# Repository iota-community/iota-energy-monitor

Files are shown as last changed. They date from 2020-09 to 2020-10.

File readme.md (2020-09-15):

# IOTA Energy Monitor

IOTA Energy Monitor

The IOTA Energy Monitor is a hardware and software project that is designed to take power and meter readings over Modbus and via CT Clamps. The device is also equipped with a CryptoCore module to enable it to issue IOTA transactions and manage funds securely. 

This repo is split into two parts:

### /hardware

This portion of the repo contains the design files for the IOTA Energy Monitor. The device was designed in EAGLE by Autodesk. 

The repo contains the lasted Gerber files in a .zip for easy reproduction.

### /software

This folder contains the micropython software for the energy meter. In order to flash it you should use the Pymakr extension of VSCode.

##### License

Apache 2.0

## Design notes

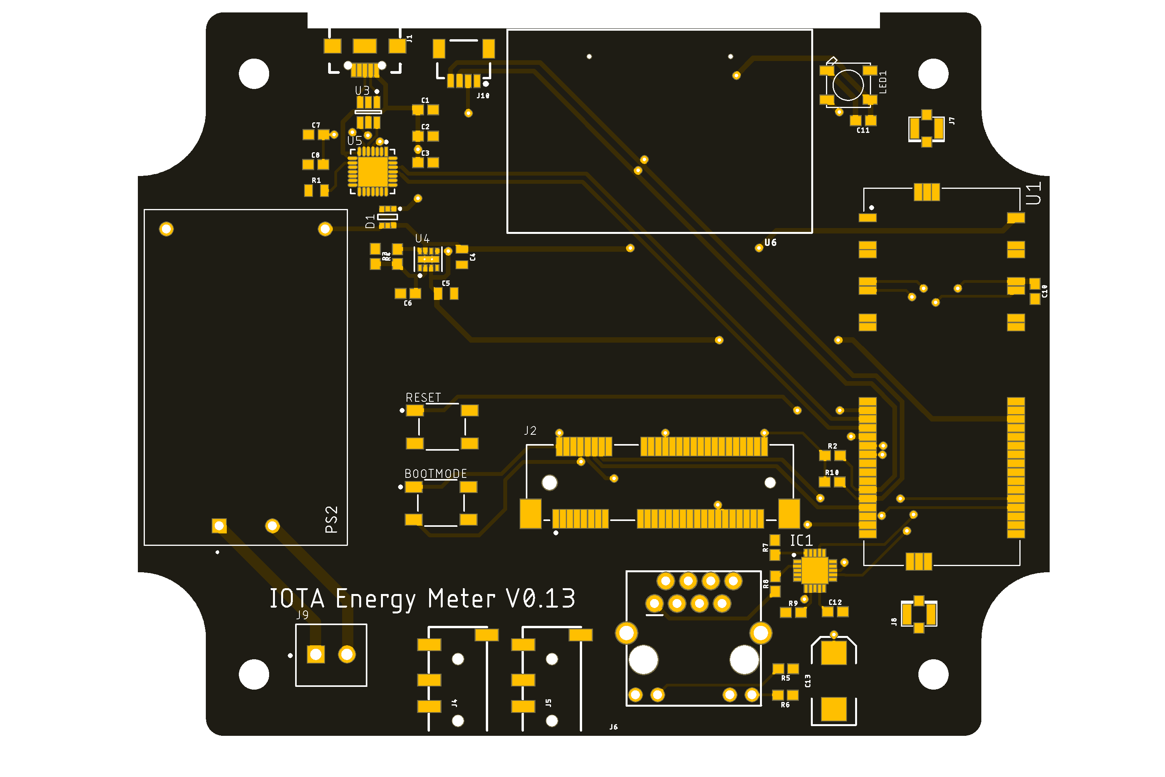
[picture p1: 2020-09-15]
hardware/iota-energy-monitor.png

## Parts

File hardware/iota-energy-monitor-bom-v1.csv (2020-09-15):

Qty | Value | Device | Package | Parts | Description | AMBIENT_TEMPERATURE_RANGE_HIGH | AMBIENT_TEMPERATURE_RANGE_LOW | AUTOMOTIVE | AVAILABILITY | CENTROID_NOT_SPECIFIED | CIIVA_IDS | COMPONENT_LINK_1_DESCRIPTION | COMPONENT_LINK_1_URL | COMPONENT_LINK_3_DESCRIPTION | COMPONENT_LINK_3_URL | CONFIGURATION | CONN_GENDER | CONN_ORIENTATION | CONTACT_MATERIAL | CURRENT_RATING | DATASHEET | DATASHEET_VERSION | DESCRIPTION | DEVICE_CLASS_L1 | DEVICE_CLASS_L2 | DEVICE_CLASS_L3 | DIGIKEY_DESCRIPTION | DIGIKEY_PART_NUMBER | FOOTPRINT_PARAMETERS_1 | FOOTPRINT_PARAMETERS_2 | FOOTPRINT_PARAMETERS_3 | FOOTPRINT_URL | FOOTPRINT_VARIANT_NAME_0 | FOOTPRINT_VARIANT_NAME_1 | FOOTPRINT_VARIANT_NAME_2 | FOOTPRINT_VARIANT_NAME_3 | HEIGHT | IMPORTED | IMPORTED_FROM | IMPORT_TS | INTERFACE | IPC_LAND_PATTERN_NAME | IS_FEMALE | LEAD_FREE | MANUFACTURER_NAME | MANUFACTURER_PART_NUMBER | MAX_JUNCTION_TEMP | MAX_SUPPLY_VOLTAGE | MEMORY_TYPE | MF | MFG_PACKAGE_IDENT | MFG_PACKAGE_IDENT_DATE | MFG_PACKAGE_IDENT_REV | MIN_SUPPLY_VOLTAGE | MOUNTING_TECHNOLOGY | MOUSER_DESCRIPTION | MOUSER_PART_NUMBER | MOUSER_PRICE-STOCK | MP
1 |  | PRT-14417 | 1X04_1MM_RA | J10 | SparkFun I2C Standard Qwiic Connector
1 |  | 1981568-1 | USB-B-MICRO-SMD | J1 | USB Type Micro-B Connector
4 | 0.1uF | C0603X104J3RACAUTO | 603 | C2, C7, C10, C11 | 0.1µF ceramic capacitors
1 | 100 | CRGCQ0603F100R | 603 | R7 | 100Ω resistor
1 | 100uF | KEMETT491D107K010AT | EIA7343 | C13 | 100µF polarized capacitors
1 | 10nF | CC0603KRX7R9BB103 | 603 | C1 | 0.01uF/10nF/10,000pF ceramic capacitors
2 | 10uF | CC0805KKX5R6BB106 | 805 | C4, C5 | 10.0µF ceramic capacitors
2 | 10uF | F380J106MMA | 0603-POLAR | C9, C14 | 10.0µF polarized capacitors
1 | 10uF | GRM188R60J106ME84D | 0805-NO | C22 | Ceramic Capacitors
1 | 118k | RK73H1JTTD1183F | 603 | R4 | Generic Resistor Package
1 | 13k | RC0603FR-0713KL | 603 | R9 | 13kΩ resistor
1 | 150k | RC0603FR-07150KL | 603 | R3 | 150kΩ resistor
1 | 1k | CRGCQ0805F1K0 | 805 | R1 | Generic Resistor Package
5 | 2.2uF | CC0805KKX7R6BB225 | 0805-NO | C20, C21, C23, C24, C25 | Ceramic Capacitors
2 | 20 | RP73PF1J20RBTDF | 603 | R12, R13 | RES-07862
3 | 220 | RC0603JR-07220RL | 603 | R5, R6, R8 | 220Ω resistor
1 | 390K | RC0805FR-07390KL | 0805-NO | R11 | Resistors
2 | 390k | RC0603FR-07390KL | 603 | R14, R15 | 390kΩ resistor
1 | 390nF | C0603C394K8PACTU | 603 | C12 | 0.39uF/390nF ceramic capacitors
2 | 4.7k | RC0603FR-074K7L | 603 | R2, R10 | 4.7kΩ resistor
2 | 4.7uF | CC0603ZRY5V5BB475 | 603 | C3, C8 | 4.7µF ceramic capacitors
1 | 470pF | 06035A471JAT2A | 603 | C6 | 470pF ceramic capacitors
2 | ALPS_SKQGAKE010ALPS_SKQGAKE010_0_0 | ALPS SKQGAKE010 | ALPS_SKQGAKE010_0 | BOOTMODE, RESET | 5.2mm Square Low-profile |  |  |  |  | No |  |  |  |  |  |  |  |  |  |  | http://www.mouser.com/ds/2/15/SKQG-180836.pdf |  |  |  |  |  |  |  |  |  |  |  |  |  |  |  |  |  |  |  |  |  |  | yes |  |  |  |  |  | ALPS |  |  |  |  |  |  | 688-SKQGAKE010
1 | ALPS_SKQGAKE010ALPS_SKQGAKE010_0_0 | ALPS SKQGAKE010 | ALPS_SKQGAKE010_0 | BOOTLOADER | 5.2mm Square Low-profile |  |  |  |  | No |  |  |  |  |  |  |  |  |  |  | http://www.mouser.com/ds/2/15/SKQG-180836.pdf |  |  |  |  |  |  |  |  |  |  |  |  |  |  |  |  |  |  |  |  |  |  | yes |  |  |  |  |  | ALPS |  |  |  |  |  |  | 688-SKQGAKE010
2 | AUDIO_JACK_TRRSSMD_RA | SJ2-3573A-SMT-TR | AUDIO_JACK_3.5MM_TRRS_SMD_RA | J4, J5 | Audio Jack - 3.5mm TRRS (SMD)
1 | HLK-5M05 | HLK-5M05 | CONV_HLK-5M05 | PS2 | AC DC 220V to 5V 5W 5Watt Isolated Switching Step-Down Power Supply Module Converter |  |  |  | Unavailable |  |  |  |  |  |  |  |  |  |  |  |  |  |  |  |  |  |  |  |  |  |  |  |  |  |  |  |  |  |  |  |  |  |  |  |  |  |  |  |  | Hi-link |  |  |  |  |  |  |  |  | HLK-5M05
1 | MAGJACK | ARJM11A1-009-AB-EW2 | MAGJACK | J6 | MAGJACK: RJ-45 with LEDs
1 | NCN5151 | NCN5151 | QFN50P400X400X100-21N | IC1 | NCN5150 Wired M-BUS Slave Transceiver |  |  |  |  |  |  |  |  |  |  |  |  |  |  |  |  |  | NCN5150 Wired M-BUS Slave Transceiver |  |  |  |  |  |  |  |  |  |  |  |  |  | 1mm |  |  |  |  |  |  |  | ON Semiconductor | NCN5151 |  |  |  |  |  |  |  |  |  |  | N/A | https://www.mouser.com/Search/Refine.aspx?Keyword=N%2FA
1 | ON_SEMICONDUCTOR_MBD330DWT1GON_SEMICONDUCTOR_MBD330DWT1G_0_0 | MBD330DWT1G | ON_SEMICONDUCTOR_MBD330DWT1G_0 | D1 | ONSC-SBD-A1K3A4K6-6 |  |  |  |  |  | 849672 | Manufacturer URL | http://www.onsemi.com/ | Package Specification | http://www.onsemi.com/pub_link/Collateral/NTJD4001N-D.PDF | Dual |  |  |  |  | http://www.onsemi.cn/pub_link/Collateral/MBD110DWT1-D.PDF | Rev. 8 |  |  |  |  |  |  |  |  |  |  | Manufacturer Recommended |  |  |  |  | yes | vault | 1521844986 |  |  |  |  |  |  |  |  |  | On Semiconductor |  |  |  |  | Surface Mount
1 | PYCOME-G01-OEM | Pycom G01 | PYCOM_PYCOME-G01-OEM | U1 | The G01 is the GPy OEM module. It’s just like the GPy but with a few bits less to make it easy to integrate. Triple network module: Cellular LTE-CAT M1/NB1, WiFi and Bluetooth. |  |  |  | Unavailable |  |  |  |  |  |  |  |  |  |  |  |  |  |  |  |  |  |  |  |  |  |  |  |  |  |  |  |  |  |  |  |  |  |  |  |  |  |  |  |  | Pycom |  |  |  |  |  |  |  |  | PYCOME-G01-OEM
1 | SILICON_LABS_CP2102N-A01-GQFN28SILICON_LABS_CP2102N-A01-GQFN28_0_3 | CP2102N-A01-GQFN28 | SILICON_LABS_CP2102N-A01-GQFN28_3 | U5 | USB Bridge, USB to UART USB 2.0 UART Interface 28-QFN (5x5) | +85°C | -40°C | No |  | No |  |  |  |  |  |  |  |  |  |  | https://media.digikey.com/pdf/Data%20Sheets/Silicon%20Laboratories%20PDFs/CP2102N_Rev.1.3_DS.pdf |  |  | Integrated Circuits (ICs) | Interface ICs | USB Interface ICs | IC BRIDGE USB TO UART 28QFN | 336-3694-ND | {fp_type":"QFN","params":{"N1":{"nom":7,"long name":"Leads on long side","min":null,"max":null,"short name":"N1","type":"count"},"N2":{"nom":7,"long name":"Leads on wide side","min":null,"max":null,"short name":"N2","type":"count"},"A":{"nom":750000,"long name":"Height","min":700000,"max":800000,"short name":"A","type":"measurement"},"A1":{"nom":false,"long name":"Package clearance","min":0,"max":50000,"short name":"A1","type":"measurement"},"A2":{"nom":false,"long name":"Package height","min":false,"max":750000,"short name":"A2","type":"measurement"},"D":{"nom":5000000,"long name":"Package length","min":4900000,"max":5100000,"short name":"D","type":"measurement"},"E":{"nom":5000000,"long name":"Package width","min":4900000,"max":5100000,"short name":"E","type":"measurement"},"B":{"nom":250000,"long name":"Lead width","min":200000,"max":300000,"short name":"B","type":"measurement"},"C":{"nom":200000,"long name":"Lead thickness","min":null,"max":null,"short name":"C","type":"measurement"},"L":{"nom":550000,"long name":"Lead foot length","min":450000,"max":650000,"short name":"L","type":"measurement"},"e":{"nom":500000,"long name":"Lead pitch","min":null,"max":null,"short name":"e","type":"measurement"},"D2":{"nom":3250000,"long name":"Thermal pad length","min":3150000,"max":false,"short name":"D2","type":"measurement"},"E2":{"nom":3250000,"long name":"Thermal pad width","min":3150000,"max":false,"short name":"E2","type":"measurement"},"PC":{"long name":"Paste coverage (%)","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 | {fp_type":"QFN","params":{"N1":{"nom":7,"long name":"Leads on long side","min":null,"max":null,"short name":"N1","type":"count"},"N2":{"nom":7,"long name":"Leads on wide side","min":null,"max":null,"short name":"N2","type":"count"},"A":{"nom":750000,"long name":"Height","min":700000,"max":800000,"short name":"A","type":"measurement"},"A1":{"nom":false,"long name":"Package clearance","min":0,"max":50000,"short name":"A1","type":"measurement"},"A2":{"nom":false,"long name":"Package height","min":false,"max":750000,"short name":"A2","type":"measurement"},"D":{"nom":5000000,"long name":"Package length","min":4900000,"max":5100000,"short name":"D","type":"measurement"},"E":{"nom":5000000,"long name":"Package width","min":4900000,"max":5100000,"short name":"E","type":"measurement"},"B":{"nom":250000,"long name":"Lead width","min":200000,"max":300000,"short name":"B","type":"measurement"},"C":{"nom":200000,"long name":"Lead thickness","min":null,"max":null,"short name":"C","type":"measurement"},"L":{"nom":550000,"long name":"Lead foot length","min":450000,"max":650000,"short name":"L","type":"measurement"},"e":{"nom":500000,"long name":"Lead pitch","min":null,"max":null,"short name":"e","type":"measurement"},"D2":{"nom":3250000,"long name":"Thermal pad length","min":3150000,"max":false,"short name":"D2","type":"measurement"},"E2":{"nom":3250000,"long name":"Thermal pad width","min":3150000,"max":false,"short name":"E2","type":"measurement"},"PC":{"long name":"Paste coverage (%)","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 | {fp_type":"QFN","params":{"N1":{"nom":7,"long name":"Leads on long side","min":null,"max":null,"short name":"N1","type":"count"},"N2":{"nom":7,"long name":"Leads on wide side","min":null,"max":null,"short name":"N2","type":"count"},"A":{"nom":750000,"long name":"Height","min":700000,"max":800000,"short name":"A","type":"measurement"},"A1":{"nom":false,"long name":"Package clearance","min":0,"max":50000,"short name":"A1","type":"measurement"},"A2":{"nom":false,"long name":"Package height","min":false,"max":750000,"short name":"A2","type":"measurement"},"D":{"nom":5000000,"long name":"Package length","min":4900000,"max":5100000,"short name":"D","type":"measurement"},"E":{"nom":5000000,"long name":"Package width","min":4900000,"max":5100000,"short name":"E","type":"measurement"},"B":{"nom":250000,"long name":"Lead width","min":200000,"max":300000,"short name":"B","type":"measurement"},"C":{"nom":200000,"long name":"Lead thickness","min":null,"max":null,"short name":"C","type":"measurement"},"L":{"nom":550000,"long name":"Lead foot length","min":450000,"max":650000,"short name":"L","type":"measurement"},"e":{"nom":500000,"long name":"Lead pitch","min":null,"max":null,"short name":"e","type":"measurement"},"D2":{"nom":3250000,"long name":"Thermal pad length","min":3150000,"max":false,"short name":"D2","type":"measurement"},"E2":{"nom":3250000,"long name":"Thermal pad width","min":3150000,"max":false,"short name":"E2","type":"measurement"},"PC":{"long name":"Paste coverage (%)","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 |  | Recommended_Land_Pattern | IPC_A | IPC_B | IPC_C | 0.8mm |  |  |  | UART,USB,RS-232,RS-485 | QFN50P500X500X75-28 |  | Yes |  |  | +105°C | 5.25V |  | Silicon Labs | CP2102N-A01-GQFN28 | 0 | 0 | 1.71V |  | IC BRIDGE USB TO UART 28QFN | 634-CP2102NA01GQFN28
1 | STMICROELECTRONICS_USBLC6-2SC6STMICROELECTRONICS_USBLC6-2SC6_0_0 | USBLC6-2SC6 | STMICROELECTRONICS_USBLC6-2SC6_0 | U3 | Very low capacitance ESD protection |  |  |  |  | No |  |  |  |  |  |  |  |  |  |  | http://www.st.com/content/ccc/resource/technical/document/datasheet/06/1d/48/9c/6c/20/4a/b2/CD00050750.pdf/files/CD00050750.pdf/jcr:content/translations/en.CD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 |  |  |  |  |  | IC TVS DIODE 5.25VWM 17VC SOT23-6 | 497-5235-1-ND |  |  |  |  |  |  |  |  |  |  |  |  |  |  |  | yes |  |  |  |  |  | STMicroelectronics |  |  |  |  |  |  | 511-USBLC6-2SC6
1 | TC2030-CTX-NL |  | TC2030-IDC-NL | J11 | Tag Connect footprint for ARM JTAG. |  |  |  | Unavailable |  |  |  |  |  |  |  |  |  |  |  |  |  | Cortex® Plug-Of-Nails™ Adapter Cable |  |  |  |  |  |  |  |  |  |  |  |  |  |  |  |  |  |  |  |  |  |  |  |  |  |  | Tag-Connect LLC |  |  |  |  |  |  |  |  | TC2030-CTX
1 | TEXAS_INSTRUMENTS_LMZ10501SILTTEXAS_INSTRUMENTS_LMZ10501SILT_0_0 | LMZ10501SILT | TEXAS_INSTRUMENTS_LMZ10501SILT_0 | U4 | Non Isolated POL DC/DC Converter, Adjustable, Micro SIP, Surface Mount Device, 1 Output, 3.6 V |  |  |  |  | No |  |  |  |  |  |  |  |  |  |  | http://www.ti.com/lit/ds/symlink/lmz10501.pdf |  |  |  |  |  | IC DC/DC CONVERTER 0.6-3.6V 1A | 296-37266-1-ND |  |  |  |  |  |  |  |  |  |  |  |  |  |  |  | yes |  |  |  |  |  | Texas Instruments | SIL0008A |  |  |  |  | Non-Isolated DC/DC Converters 1A Nano Mod w/ 5.5V Max Inpt VTG | 595-LMZ10501SILT
1 | TE_1775838-2TE_1775838-2_0_0 | 1775838-2 | TE_1775838-2_0 | J2 | Conn Mini PCI Express Card Edge SKT 52 POS Solder RA SMD T/R |  |  |  |  | No |  |  |  |  |  |  | Female | Vertical | Gold,Nickel |  | https://www.te.com/commerce/DocumentDelivery/DDEController?Action=showdoc |  |  | Connectors | Card Edge Connectors | unset | CONN PCI EXP MINI FEMALE 52POS | A123340CT-ND |  |  |  | https://www.te.com/commerce/DocumentDelivery/DDEController?Action=showdoc |  |  |  |  | 5.9mm |  |  |  |  |  | yes | yes |  |  |  |  |  | TE | 1775838-2 | 0 | 0 |  |  | Conn Mini PCI Express Card Edge SKT 52 POS Solder RA SMD T/R | 571-1775838-2
1 | TE_1776275-2TE_1776275-2_0_0 | 1776275-2 | TE_1776275-2_0 | J9 | 2 Position Wire to Board Terminal Block Horizontal with Board 0.138 (3.50mm) Through Hole" |  |  |  |  | No |  |  |  |  |  |  |  |  |  |  | http://www.te.com/commerce/DocumentDelivery/DDEController?Action=showdoc |  |  |  |  |  | CONN TERM BLOCK 2POS SIDE ENT 3.5MM | A98036-ND |  |  |  |  |  |  |  |  |  |  |  |  |  |  | yes | yes |  |  |  |  |  | TE |  |  |  |  |  |  | 571-1776275-2
2 | U.FL | WRL-09144 | U.FL | J7, J8 | SMD Antenna Connector - U.FL
1 | UG-2864HSWEG01 | UG-2864HSWEG01 | UG-2864HSWEG01_1.3_WRAPAROUND | U6 | UG-2864HSWEG01 OLED display
1 | WS2812B5050 | WS2812B5050 | WS2812B | LED1 |  |  |  |  | Unavailable |  |  |  |  |  |  |  |  |  |  |  |  |  | Raspberry Pi HAT _40 pin_ Wheeled Robotics Kit |  |  |  |  |  |  |  |  |  |  |  |  |  |  |  |  |  |  |  |  |  |  |  |  |  |  | SparkFun Electronics |  |  |  |  |  |  |  |  | WS2812B
1 | WURTH_ELECTRONICS_INC._693043020611WURTH_ELECTRONICS_INC._693043020611_0_0 | 693043020611 | WURTH_ELECTRONICS_INC._693043020611_0 | J3 | 6 Position Card Connector NANO SIM Surface Mount, Right Angle Gold |  |  |  |  | No |  |  |  |  |  |  |  | Right Angle | Gold | 1A | http://katalog.we-online.de/em/datasheet/693043020611.pdf |  |  | Connectors | Memory Connectors | unset | CONN SMART CARD PUSH-PULL | 732-5954-1-ND |  |  |  |  |  |  |  |  | 1.35mm |  |  |  |  |  | yes | yes |  |  |  |  | OTHER | Wurth Electronics Inc. | 693043020611 | 0 | 0 |  |  |  | 710-693043020611
1 | LTE-m Cat1 Antenna | MFX3.07.0150C
1 | 2.4gh antenna | W2.4-5P-U
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

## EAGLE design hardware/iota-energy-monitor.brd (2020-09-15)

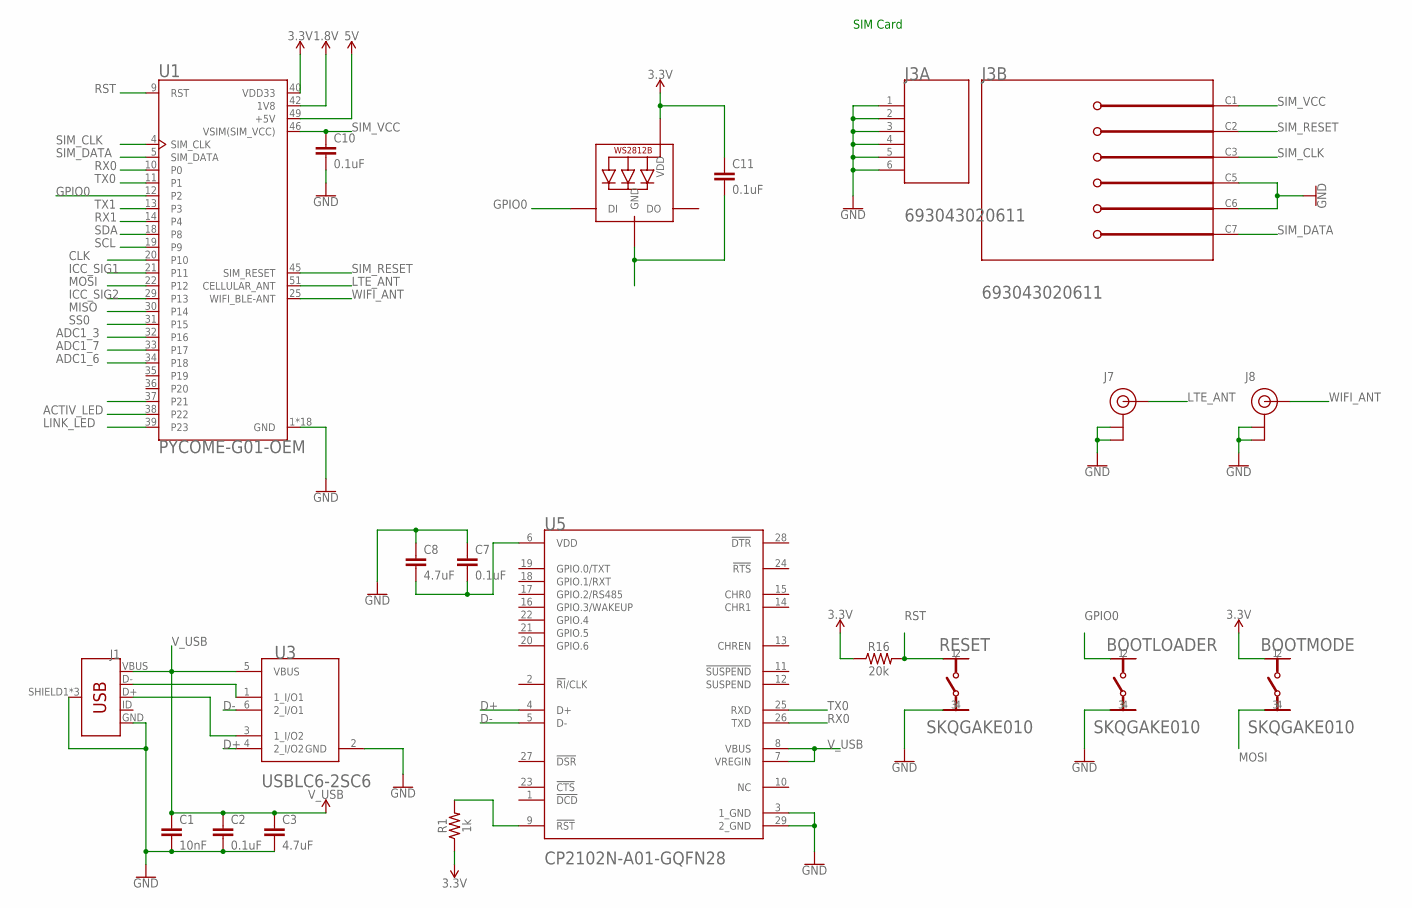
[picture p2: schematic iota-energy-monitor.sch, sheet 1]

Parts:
BOOTLOADER: ALPS_SKQGAKE010ALPS_SKQGAKE010_0_0; ALPS_SKQGAKE010_0
BOOTMODE: ALPS_SKQGAKE010ALPS_SKQGAKE010_0_0; ALPS_SKQGAKE010_0
C1: 10nF; 0603
C2, C7, C10, C11: 0.1uF; 0603
C3, C8: 4.7uF; 0603
J1: USB_MICRO-B_FEMALE-SMT; USB-B-MICRO-SMD
J3: WURTH_ELECTRONICS_INC._693043020611WURTH_ELECTRON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; WURTH_ELECTRONICS_INC._693043020611_0
J7, J8: U.FL
LED1: WS2812B5050; WS2812B
R1: 1k; 0805
R16: 20k; 0603
RESET: ALPS_SKQGAKE010ALPS_SKQGAKE010_0_0; ALPS_SKQGAKE010_0
U1: PYCOME-G01-OEM; PYCOM_PYCOME-G01-OEM
U3: STMICROELECTRONICS_USBLC6-2SC6STMICROELECTRONICS_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; STMICROELECTRONICS_USBLC6-2SC6_0
U5: SILICON_LABS_CP2102N-A01-GQFN28SILICON_LABS_CP210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; SILICON_LABS_CP2102N-A01-GQFN28_3

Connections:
1.8V: U1.42 (1V8)
3.3V: BOOTMODE.1, C11.1, LED1.1-VDD (VDD), R1.1, R16.1, U1.40 (VDD33); also elsewhere on the board
5V: U1.49 (+5V); also elsewhere on the board
ACTIV_LED: U1.38 (P22); also elsewhere on the board
ADC1_3: U1.32 (P16); also elsewhere on the board
ADC1_6: U1.34 (P18)
ADC1_7: U1.33 (P17); also elsewhere on the board
CLK: U1.20 (P10); also elsewhere on the board
D+: U3.4 (2_I/O2), U5.4 (D+)
D-: U3.6 (2_I/O1), U5.5 (D-)
GND: BOOTLOADER.3, C1.2, C2.2, C3.2, C7.1, C8.1, C10.2, J1.GND, J1.SHIELD1 (SHIELD), J1.SHIELD2 (SHIELD), J1.SHIELD3 (SHIELD), J3.1 (MNT_1), J3.2 (MNT_2), J3.3 (MNT_3), J3.4 (MNT_4), J3.5 (MNT_5), J3.6 (MNT_6), J3.C5 (GROUND(GND)), J3.C6 (PROGRAMMING_VOLTAGE(VPP)), J7.1 (GND), J7.2 (GND), J8.1 (GND), J8.2 (GND), RESET.3, U1.1 (GND), U1.2 (GND), U1.3 (GND), U1.6 (GND), U1.7 (GND), U1.8 (GND), U1.23 (GND), U1.24 (GND), U1.26 (GND), U1.27 (GND), U1.28 (GND), U1.41 (GND), U1.43 (GND), U1.44 (GND), U1.47 (GND), U1.48 (GND), U1.50 (GND), U1.52 (GND), U3.2 (GND), U5.3 (1_GND), U5.29 (2_GND); also elsewhere on the board
GPIO0: BOOTLOADER.1, LED1.4-DIN (DI), U1.12 (P2)
ICC_SIG1: U1.21 (P11); also elsewhere on the board
ICC_SIG2: U1.29 (P13); also elsewhere on the board
LINK_LED: U1.39 (P23); also elsewhere on the board
LTE_ANT: J7.FEED (SIGNAL), U1.51 (CELLULAR_ANT)
MISO: U1.30 (P14); also elsewhere on the board
MOSI: BOOTMODE.3, U1.22 (P12); also elsewhere on the board
unnamed: R1.2, U5.9 (!RST!)
unnamed: C7.2, C8.2, U5.6 (VDD)
unnamed: C11.2, LED1.3-GND (GND)
unnamed: J1.D-, U3.1 (1_I/O1)
unnamed: J1.D+, U3.3 (1_I/O2)
RST: R16.2, RESET.1, U1.9 (RST)
RX0: U1.10 (P0), U5.26 (TXD)
RX1: U1.14 (P4); also elsewhere on the board
SCL: U1.19 (P9); also elsewhere on the board
SDA: U1.18 (P8); also elsewhere on the board
SIM_CLK: J3.C3 (CLOCK(CLK)), U1.4 (SIM_CLK)
SIM_DATA: J3.C7 (I/O), U1.5 (SIM_DATA)
SIM_RESET: J3.C2 (RESET(RST)), U1.45 (SIM_RESET)
SIM_VCC: C10.1, J3.C1 (SUPPLY_VOLTAGE(VCC)), U1.46 (VSIM(SIM_VCC))
SS0: U1.31 (P15); also elsewhere on the board
TX0: U1.11 (P1), U5.25 (RXD)
TX1: U1.13 (P3); also elsewhere on the board
V_USB: C1.1, C2.1, C3.1, J1.VBUS, U3.5 (VBUS), U5.7 (VREGIN), U5.8 (VBUS); also elsewhere on the board
WIFI_ANT: J8.FEED (SIGNAL), U1.25 (WIFI_BLE-ANT)

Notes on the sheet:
SIM Card

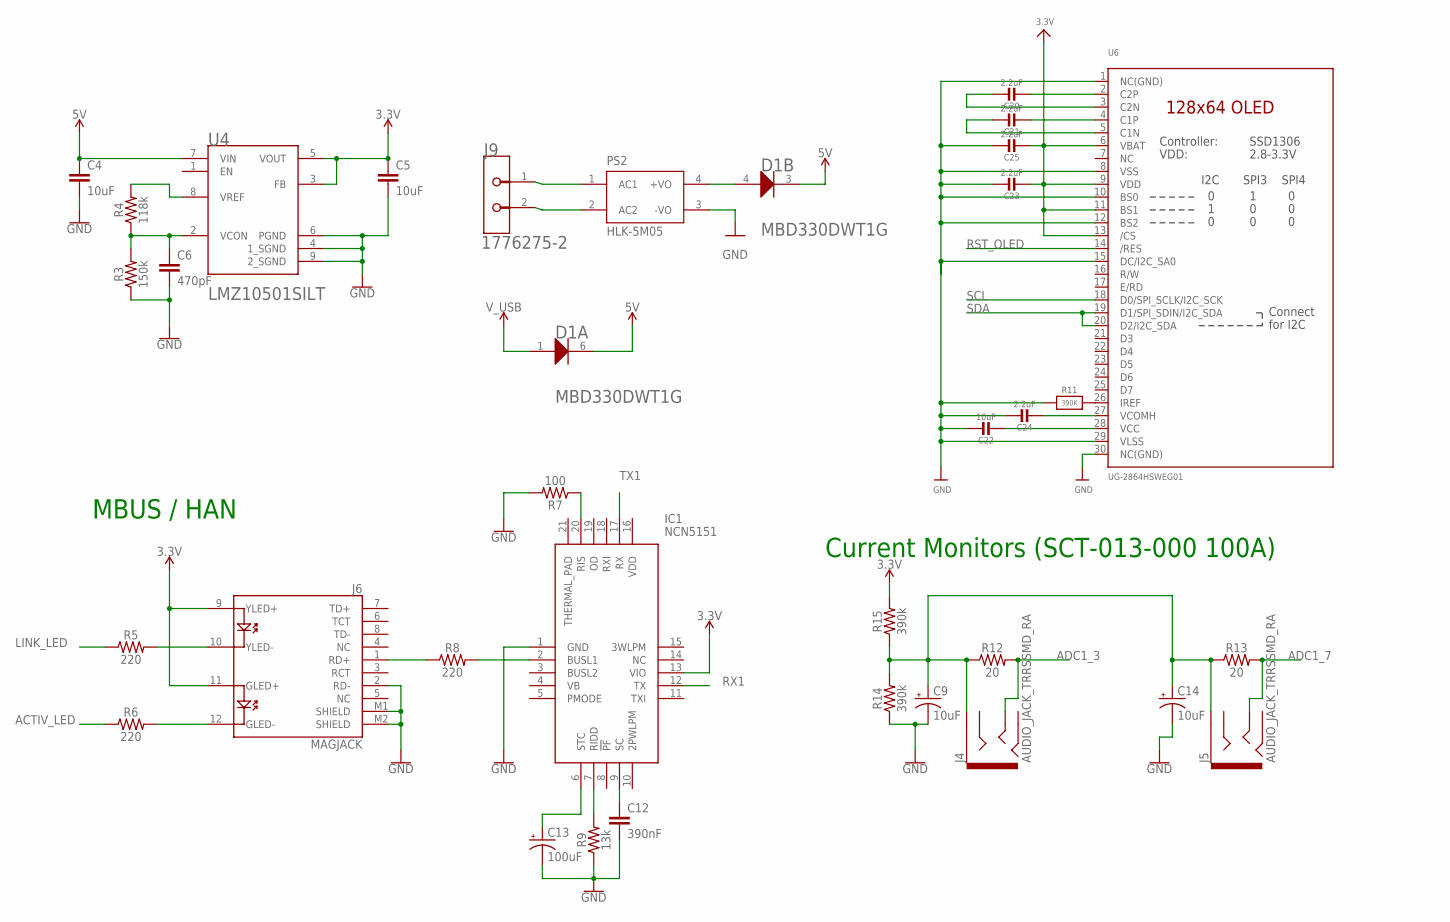
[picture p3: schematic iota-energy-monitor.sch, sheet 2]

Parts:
C4, C5: 10uF; 0805
C6: 470pF; 0603
C9, C14: 10uF; 0603-POLAR
C12: 390nF; 0603
C13: 100uF; EIA7343
C20, C21, C23, C24, C25: 2.2uF; 0805-NO; MPN C2012X7R1C225K125AB
C22: 10uF; 0805-NO; MPN GRM188R60J106ME84D
D1: ON_SEMICONDUCTOR_MBD330DWT1GON_SEMICONDUCTOR_MBD3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; ON_SEMICONDUCTOR_MBD330DWT1G_0
IC1: NCN5151; QFN50P400X400X100-21N
J4, J5: AUDIO_JACK_TRRSSMD_RA; AUDIO_JACK_3.5MM_TRRS_SMD_RA
J6: MAGJACK
J9: TE_1776275-2TE_1776275-2_0_0; TE_1776275-2_0
PS2: HLK-5M05; CONV_HLK-5M05
R3: 150k; 0603
R4: 118k; 0603
R5, R6, R8: 220; 0603
R7: 100; 0603
R9: 13k; 0603
R11: 390K; 0805-NO; MPN CRGCQ0603F390K
R12, R13: 20; 0603
R14, R15: 390k; 0603
U4: TEXAS_INSTRUMENTS_LMZ10501SILTTEXAS_INSTRUMENTS_L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; TEXAS_INSTRUMENTS_LMZ10501SILT_0
U6: UG-2864HSWEG01; UG-2864HSWEG01_1.3_WRAPAROUND; MPN UG-2864HSWEG01

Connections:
3.3V: C5.1, C23.2, C25.2, IC1.13 (VIO), J6.9 (YLED+), J6.11 (GLED+), R15.2, U4.3 (FB), U4.5 (VOUT), U6.6 (VBAT), U6.9 (VDD), U6.11 (BS1), U6.13 (/CS); also elsewhere on the board
5V: C4.1, D1.3 (K1), D1.6 (K2), U4.7 (VIN); also elsewhere on the board
ACTIV_LED: R6.1; also elsewhere on the board
ADC1_3: J4.TIP, R12.2; also elsewhere on the board
ADC1_7: J5.TIP, R13.2; also elsewhere on the board
GND: C4.2, C5.2, C6.2, C9.-, C12.2, C13.C (-), C14.-, C22.1, C23.1, C24.1, C25.1, IC1.1 (GND), J6.2 (RD-), J6.M1 (SHIELD), J6.M2 (SHIELD), PS2.3 (-VO), R3.1, R7.2, R9.1, R11.1, R14.1, U4.4 (1_SGND), U4.6 (PGND), U4.9 (2_SGND), U6.1 (NC(GND)), U6.8 (VSS), U6.10 (BS0), U6.12 (BS2), U6.15 (DC/I2C_SA0), U6.29 (VLSS), U6.30 (NC(GND)); also elsewhere on the board
LINK_LED: R5.1; also elsewhere on the board
unnamed: C6.1, R3.2, R4.1, U4.2 (VCON)
unnamed: R4.2, U4.8 (VREF)
unnamed: J6.1 (RD+), R8.1
unnamed: J9.1, PS2.1 (AC1)
unnamed: J9.2, PS2.2 (AC2)
unnamed: D1.4 (A1), PS2.4 (+VO)
unnamed: IC1.2 (BUSL1), R8.2
unnamed: C12.1, IC1.9 (SC)
unnamed: J6.10 (YLED-), R5.2
unnamed: J6.12 (GLED-), R6.2
unnamed: IC1.7 (RIDD), R9.2
unnamed: C13.A (+), IC1.6 (STC)
unnamed: IC1.20 (RIS), R7.1
unnamed: R11.2, U6.26 (IREF)
unnamed: C9.+, C14.+, J4.EARTH, J5.EARTH, R12.1, R13.1, R14.2, R15.1
unnamed: C20.2, U6.2 (C2P)
unnamed: C20.1, U6.3 (C2N)
unnamed: C21.2, U6.4 (C1P)
unnamed: C21.1, U6.5 (C1N)
unnamed: C22.2, U6.28 (VCC)
unnamed: C24.2, U6.27 (VCOMH)
RST_OLED: U6.14 (/RES)
RX1: IC1.12 (TX); also elsewhere on the board
SCL: U6.18 (D0/SPI_SCLK/I2C_SCK); also elsewhere on the board
SDA: U6.19 (D1/SPI_SDIN/I2C_SDA), U6.20 (D2/I2C_SDA); also elsewhere on the board
TX1: IC1.17 (RX); also elsewhere on the board
V_USB: D1.1 (A2); also elsewhere on the board

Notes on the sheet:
MBUS / HAN
Current Monitors (SCT-013-000 100A)

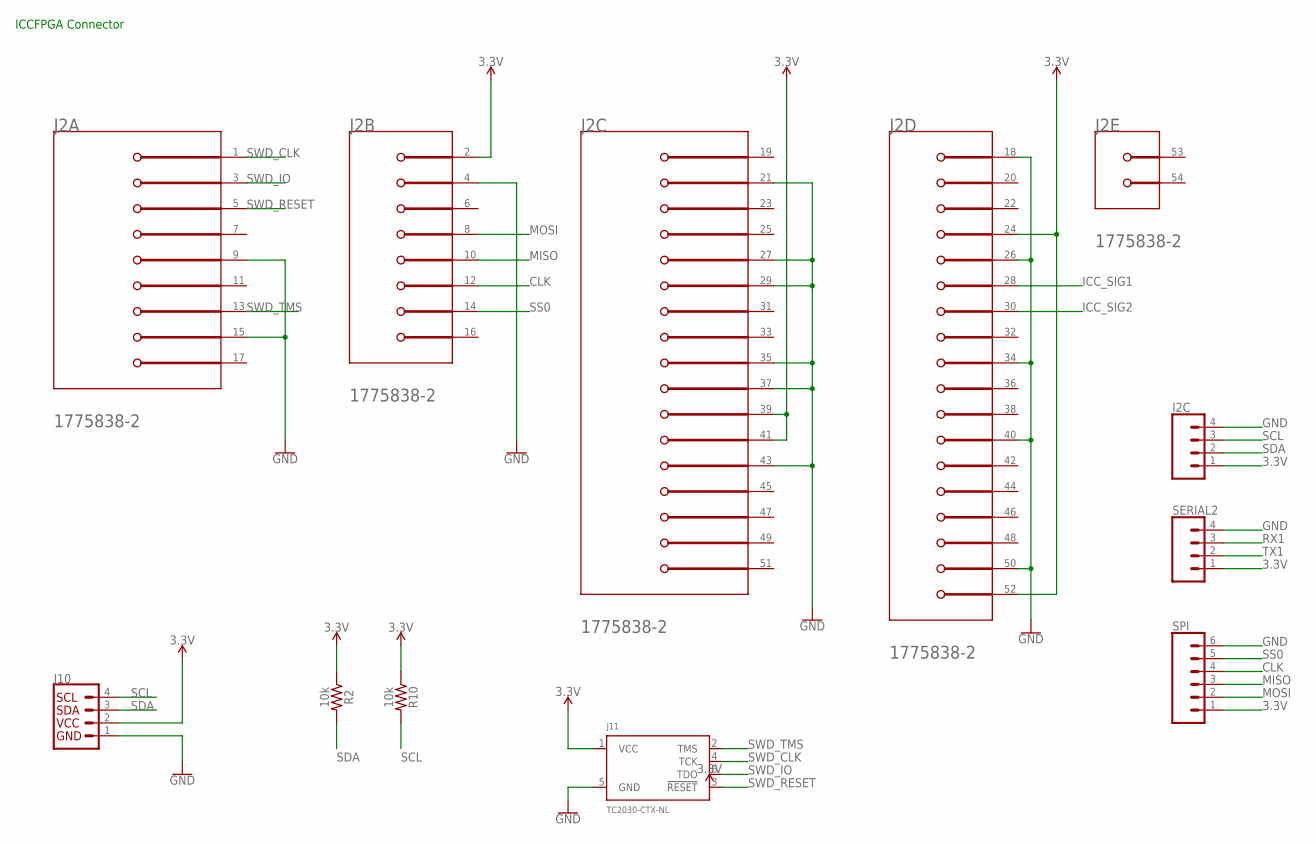
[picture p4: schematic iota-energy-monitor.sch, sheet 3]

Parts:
I2C: CONN_04POLAR_LOCK; MOLEX-1X4_LOCK
J2: TE_1775838-2TE_1775838-2_0_0; TE_1775838-2_0
J10: QWIIC_CONNECTORJS-1MM; 1X04_1MM_RA
J11: TC2030-CTX-NL; TC2030-IDC-NL
R2, R10: 10k; 0603
SERIAL2: CONN_04POLAR_LOCK; MOLEX-1X4_LOCK
SPI: CONN_06POLAR_LOCK; MOLEX-1X6_LOCK

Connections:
1.5V: J2.6 (1.5V)
2_+1.5V: J2.48 (2_+1.5V)
3.3V: I2C.1, J2.2 (3.3VAUX), J2.24 (1_+3.3VAUX), J2.39 (2_+3.3VAUX), J2.41 (3_+3.3VAUX), J2.52 (4_+3.3VAUX), J10.2 (VCC), J11.1 (VCC), R2.1, R10.1, SERIAL2.1, SPI.1; also elsewhere on the board
CLK: J2.12 (UIM_CLK), SPI.4; also elsewhere on the board
GND: I2C.4, J2.4 (1_GND), J2.9 (2_GND), J2.15 (3_GND), J2.18 (4_GND), J2.21 (5_GND), J2.26 (6_GND), J2.27 (7_GND), J2.29 (8_GND), J2.34 (9_GND), J2.35 (10_GND), J2.37 (11_GND), J2.40 (12_GND), J2.43 (13_GND), J2.50 (14_GND), J10.1 (GND), J11.5 (GND), SERIAL2.4, SPI.6; also elsewhere on the board
ICC_SIG1: J2.28 (1_+1.5V); also elsewhere on the board
ICC_SIG2: J2.30 (SMB_CLK); also elsewhere on the board
MISO: J2.10 (UIM_DATA), SPI.3; also elsewhere on the board
MOSI: J2.8 (UIM_PWR), SPI.2; also elsewhere on the board
RX1: SERIAL2.3; also elsewhere on the board
SCL: I2C.3, J10.4 (SCL), R10.2; also elsewhere on the board
SDA: I2C.2, J10.3 (SDA), R2.2; also elsewhere on the board
SS0: J2.14 (UIM_RESET), SPI.5; also elsewhere on the board
SWD_CLK: J2.1 (!WAKE!), J11.4 (TCK)
SWD_IO: J2.3 (COEX1), J11.6 (TDO)
SWD_RESET: J2.5 (COEX2), J11.3 (!RESET)
SWD_TMS: J2.13 (REFCLK+), J11.2 (TMS)
TX1: SERIAL2.2; also elsewhere on the board
UIM_VPP: J2.16 (UIM_VPP)

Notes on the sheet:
ICCFPGA Connector

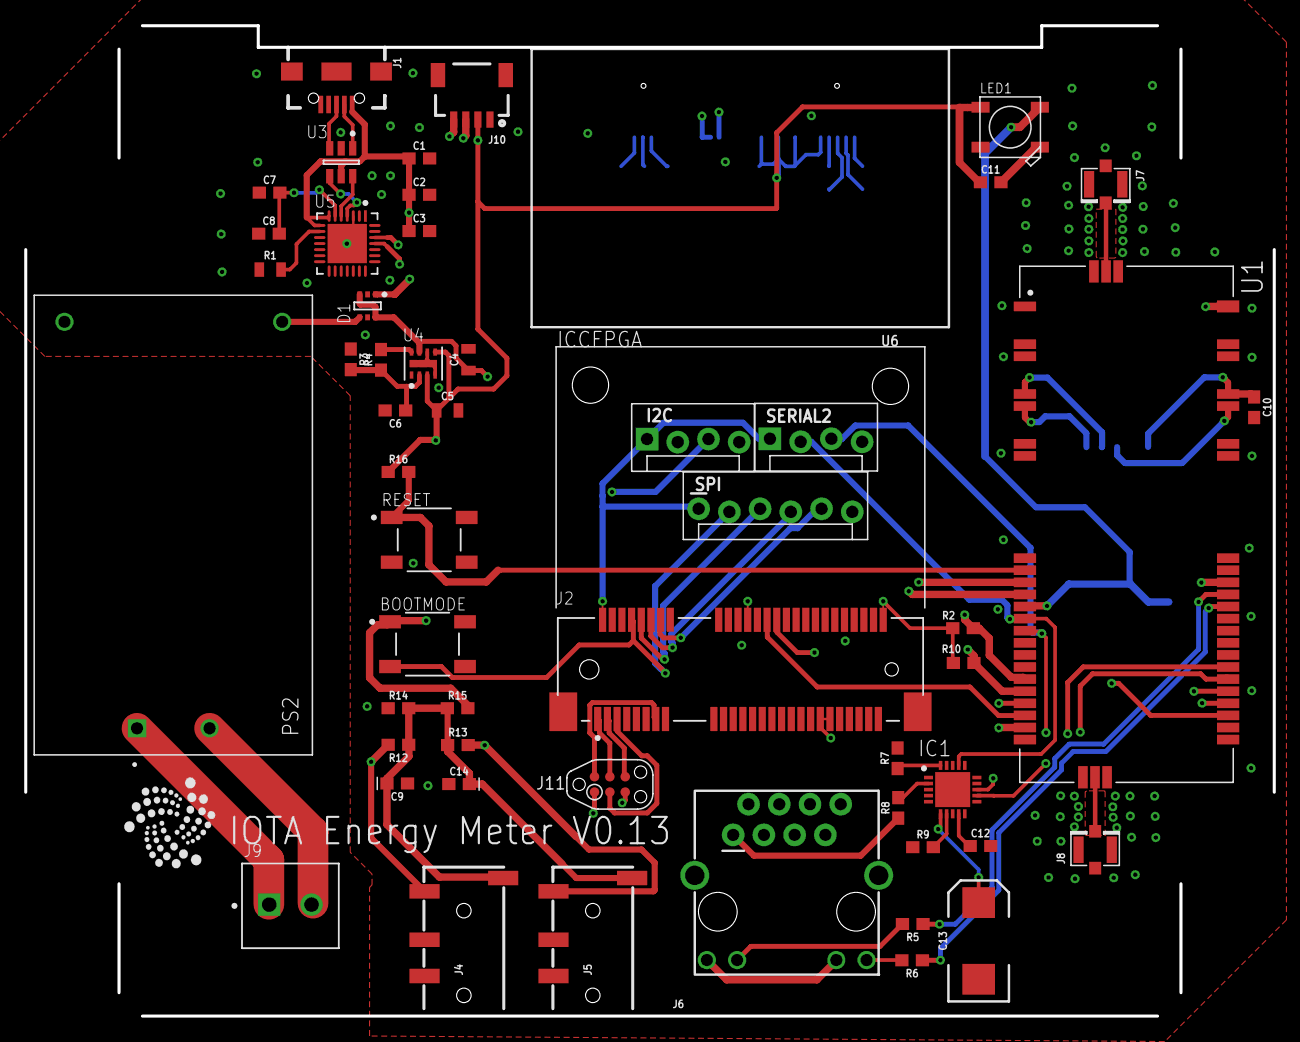
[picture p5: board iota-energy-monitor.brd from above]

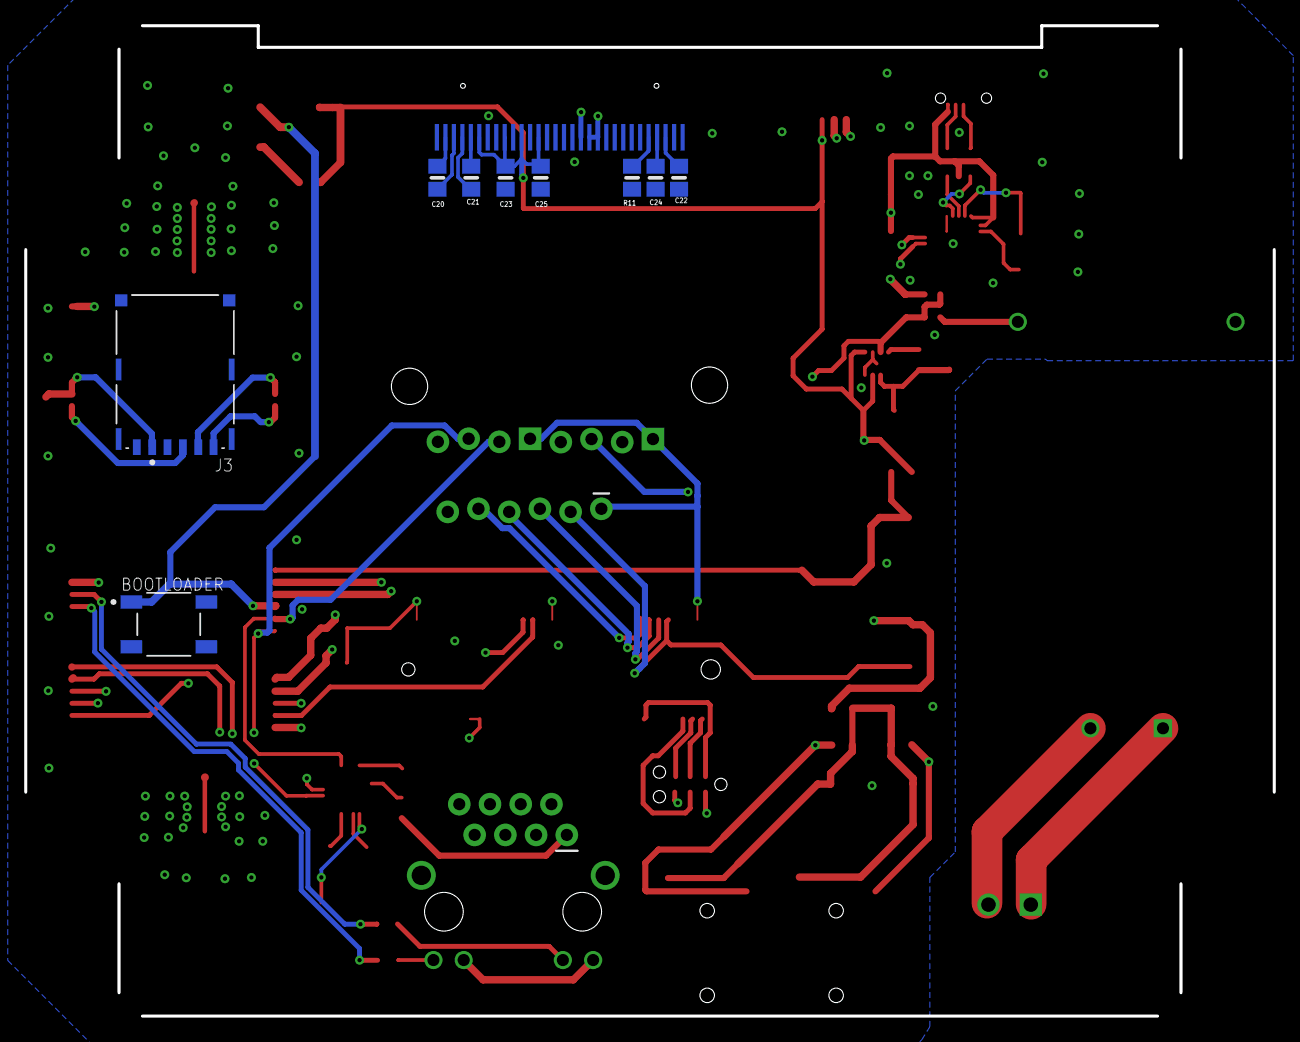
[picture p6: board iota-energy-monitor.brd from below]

Board: 4 copper layers, 103.2 x 81.9 mm, 62 parts (9 on the bottom side), 60 nets.

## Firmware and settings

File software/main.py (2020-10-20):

import utime
import machine
import socket
import ssl
import time

from network import WLAN
from network import LTE
from libs import rgbled
from libs import kv
from libs import screen
from libs import wifi
from libs import emonlib
from libs import urequests

########
## Setup Section

# Setup pin for ADC coversion
adc = machine.ADC()  # create an ADC object
# Load up the Python Emon lib
emon1 = emonlib.Emonlib()
# Fetch data stored in the devices' Key/Value store
config = kv.getAll()
print(config)
#Setup RGB LED
rgbled.init()
rgbled.green()
# Initalise Screen
oled = screen.init()

# Read Current from the meter
def getCurrent():
    print("Fetching")
    emon1.current("P16", 144.43)
    return emon1.calc_current_rms(1480)

# Main application loop
def main():
    while True:
        amps = getCurrent()
        watts = amps / 1000 * 240
        print("Current MilliAmps: ", amps)
        print("Current Watts: ", amps / 1000 * 240)
        oled.fill(0)
        if watts > 5:
            oled.text("PowerConsumption", 0, 0)
            oled.text("Watts: {}".format(watts), 0, 15)

            response = urequests.request(
                "POST", "http://{}:{}/{}".format(config['IOTA_ENDPOINT'],
                                                      config['IOTA_PORT'], config['MODE']),
                '{"uuid": "' + str(config['UUID']) + '","energy":' +
                str(watts) + '}', None, {
                    "Content-Type": "application/json"
                }).text
            print(response)
        else:
            oled.text("Please connect", 0, 0)
            oled.text("CT Clamp", 0, 15)
        oled.show()

        utime.sleep_ms(10000)

# Change boot up sequence depending on wifi setup.
if config['AP_SSID'] == False:
    # Display instructions
    oled.fill(0)
    oled.text("Setting up", 0, 0)
    oled.text("WiFi network", 0, 15)
    oled.show()
    #Start WiFi Station for config updates
    wifi.create_wifi()

    # Import and Start Webserver
    import webserver
    server = webserver.init()
    server.StartManaged()

    # Display instructions
    oled.fill(0)
    oled.text("Join WiFi:", 0, 0)
    oled.text("IOTA-CXC-MODULE", 0, 15)
    oled.text("Navigate to:", 0, 40)
    oled.text("192.168.4.1", 0, 55)
    oled.show()
    utime.sleep_ms(1000)

else:
    wifi.connect_wifi(config['AP_SSID'], config['AP_PWD'], oled)
    print("Connected to WiFi")
    main()

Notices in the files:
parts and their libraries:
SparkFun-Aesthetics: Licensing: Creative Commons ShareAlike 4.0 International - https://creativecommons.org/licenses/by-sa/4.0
